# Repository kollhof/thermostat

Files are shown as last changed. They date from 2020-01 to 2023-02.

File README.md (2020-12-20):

# thermostat
ESP32 based thermostat for a DIY heating system

## gettting started

Create a factory NVS partitions with hardware and homekit config:

```bash
../esp-homekit-sdk/tools/mfg_homekit/hk_mfg_gen.py --conf mfg-config.csv --values mfg-values.csv --prefix thermo --cid 9 --outdir ./secret/mfg/ --size 0x6000
```

Flash factory partitions to individual devices:

```bash
esptool.py write_flash 0x340000 secret/mfg/bin/thermo-[homekit-setup-id].bin
```

Flash firmware:

```bash
idf.py clean build flash
```

Update firmware over the air:

The Device ID can be found as serial number in Homekit once paired.
```bash
idf.py -DOTA_DEVICE_ID=[device-id] clean build flash-ota
```

## progress

This first version used an ESP32-WROVER-V4 powered by a Hi-link power supply all badly soldered to a protboard with way too thick wires.

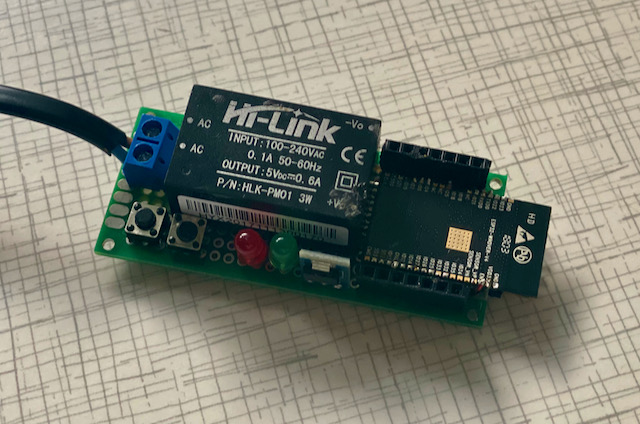
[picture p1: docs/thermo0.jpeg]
prototype 0


After reading up on powersupplies I decided to ditch the Hi-link for a Recom RAC03-05SK. It does not need any extra components to be safe which made things a bit simpler.

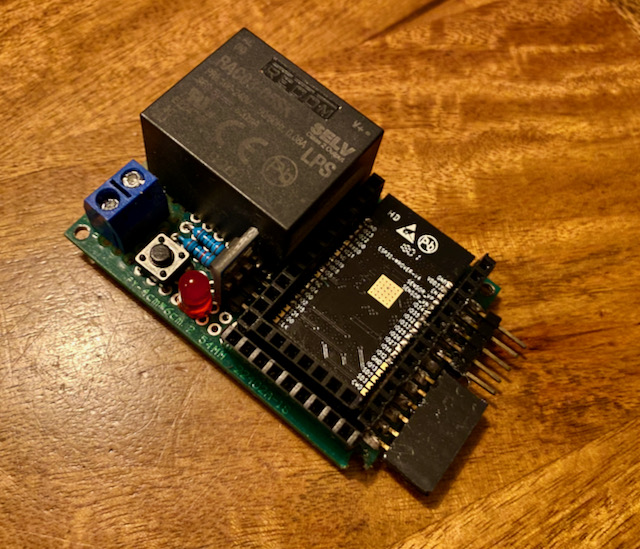
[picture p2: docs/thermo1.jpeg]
prototype 1


The female pin headers were awful to work with and I wanted a bit more ports exposed for experimenting.

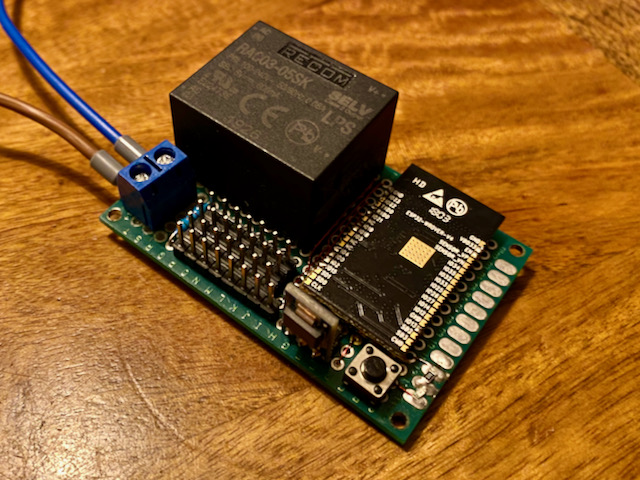
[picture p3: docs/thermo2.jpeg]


I also started to get a tiny bit better at soldering, and my choice of wires improved as well.

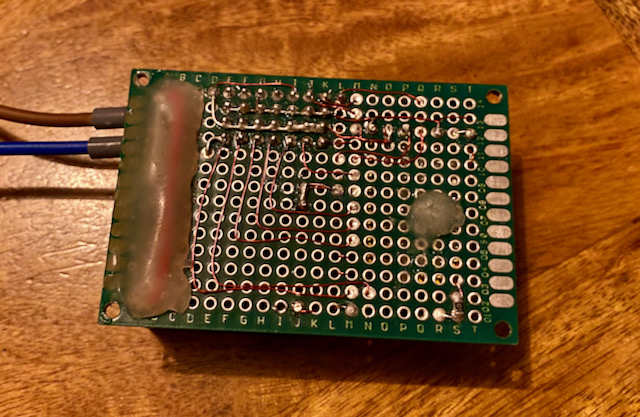
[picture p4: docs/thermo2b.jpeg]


Now I had a pretty well working little board. I used Dallas ds18b20 sensors to measure temperatur and relays to drive the electric radiators.

I needed about 5 of these boards, wiring and soldering everything got old pretty quickly. Instead of continuing to use protoboards, I decided to design my own PCB. I downloaded KiCad, looked at many ESP-32 dev board schematics for inspiration and created my own little board.

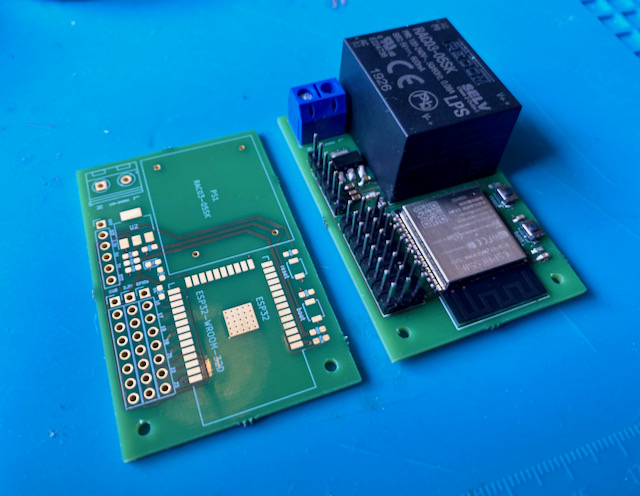
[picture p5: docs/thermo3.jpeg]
prototype 3


I had them printed by https://aisler.net and few days later I had a 3 PCBs and all the parts needed. I soldered all the SMD components using a hot air blower,and everything just worked!

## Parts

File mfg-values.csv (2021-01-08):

hw_model | hw_rev | gpio_led | gpio_pwm | gpio_temp | heat_min | heat_normal | heat_max | heat_cycle | ota_uri | ota_cert | mqtt_uri | root_cert_pem | client_cert_pem | client_key_pem
pico32 | 0.0.1 | 25 | 26 | 19 | 5 | 50 | 80 | 10 | secret/ota/ota-uri.txt | secret/ota/ota_ca_cert.pem | secret/aws/mqtt-uri.txt | secret/aws/aws-root-ca.pem | secret/aws/aws-certificate.pem.crt | secret/aws/aws-private.pem.key
proto1 | 0.0.1 | 18 | 27 | 25 | 5 | 50 | 80 | 10 | secret/ota/ota-uri.txt | secret/ota/ota_ca_cert.pem | secret/aws/mqtt-uri.txt | secret/aws/aws-root-ca.pem | secret/aws/aws-certificate.pem.crt | secret/aws/aws-private.pem.key
proto2 | 0.0.2 | 32 | 19 | 21 | 5 | 50 | 80 | 10 | secret/ota/ota-uri.txt | secret/ota/ota_ca_cert.pem | secret/aws/mqtt-uri.txt | secret/aws/aws-root-ca.pem | secret/aws/aws-certificate.pem.crt | secret/aws/aws-private.pem.key
proto4 | 0.0.4 | 13 | 22 | 23 | 5 | 50 | 80 | 10 | secret/ota/ota-uri.txt | secret/ota/ota_ca_cert.pem | secret/aws/mqtt-uri.txt | secret/aws/aws-root-ca.pem | secret/aws/aws-certificate.pem.crt | secret/aws/aws-private.pem.key
therm1 | 0.0.2 | 2 | 16 | 4 | 5 | 50 | 80 | 10 | secret/ota/ota-uri.txt | secret/ota/ota_ca_cert.pem | secret/aws/mqtt-uri.txt | secret/aws/aws-root-ca.pem | secret/aws/aws-certificate.pem.crt | secret/aws/aws-private.pem.key
therm1 | 0.0.2 | 2 | 16 | 4 | 5 | 50 | 80 | 10 | secret/ota/ota-uri.txt | secret/ota/ota_ca_cert.pem | secret/aws/mqtt-uri.txt | secret/aws/aws-root-ca.pem | secret/aws/aws-certificate.pem.crt | secret/aws/aws-private.pem.key
therm1 | 0.0.2 | 2 | 16 | 4 | 5 | 50 | 80 | 10 | secret/ota/ota-uri.txt | secret/ota/ota_ca_cert.pem | secret/aws/mqtt-uri.txt | secret/aws/aws-root-ca.pem | secret/aws/aws-certificate.pem.crt | secret/aws/aws-private.pem.key

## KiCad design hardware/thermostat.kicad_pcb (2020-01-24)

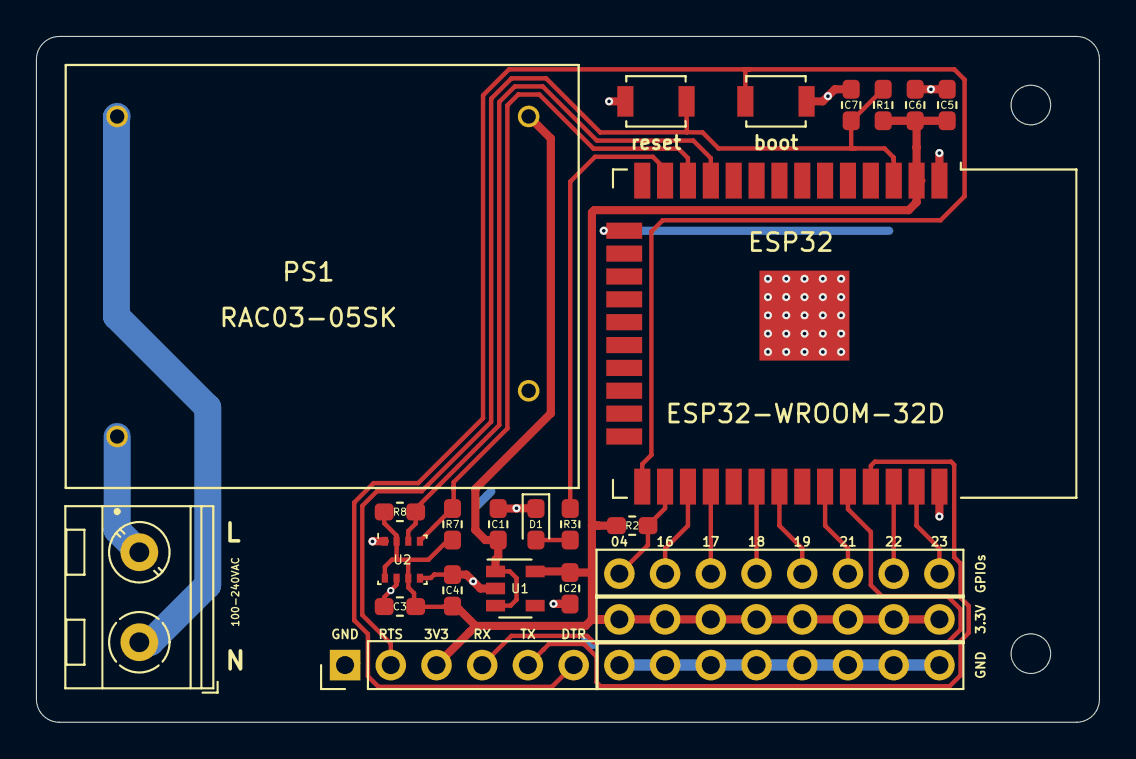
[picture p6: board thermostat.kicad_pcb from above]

Board: 2 copper layers, 59.1 x 38.1 mm, 27 parts (1 on the bottom side), 21 nets.

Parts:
C1: 1.0uF; C_0603_1608Metric_Pad1.05x0.95mm_HandSolder
C2: 2.2uF; C_0603_1608Metric_Pad1.05x0.95mm_HandSolder
C3, C4, C6, C7: 0.1uF; C_0603_1608Metric_Pad1.05x0.95mm_HandSolder
C5: 22uF; C_0603_1608Metric_Pad1.05x0.95mm_HandSolder
D1: status; LED_0603_1608Metric_Pad1.05x0.95mm_HandSolder
ESP32: ESP32-WROOM-32D; ESP32-WROOM-32
H1, H2: MountingHole; MountingHole_2.2mm_M2_ISO7380
J1: 230AC; TerminalBlock_RND_205-00045_1x02_P5.00mm_Horizontal
J2: program; PinHeader_1x06_P2.54mm_Vertical
J3: 3.3V; PinHeader_1x08_P2.54mm_Vertical
J4: GND; PinHeader_1x08_P2.54mm_Vertical
J5: GPIOs; PinHeader_1x08_P2.54mm_Vertical
LOGO1: Logo_Open_Hardware_Small; OSHW-Symbol_6.7x6mm_SilkScreen
PS1: RAC03-05SK; CONV_RAC03-05SK
R1: 10K; R_0603_1608Metric_Pad1.05x0.95mm_HandSolder
R2, R7, R8: 4.7k; R_0603_1608Metric_Pad1.05x0.95mm_HandSolder
R3: 1k; R_0603_1608Metric_Pad1.05x0.95mm_HandSolder
SW1: reset; SW_SPST_B3U-1000P
SW2: boot; SW_SPST_B3U-1000P
U1: AP2112K-3.3; SOT-23-5
U2: BME280; Bosch_LGA-8_2.5x2.5mm_P0.65mm_ClockwisePinNumbering

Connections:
+3V3: C2.1, C3.1, C4.1, C5.1, C6.1, ESP32.2, J2.3, J3.1, J3.2, J3.3, J3.4, J3.5, J3.6, J3.7, J3.8, R1.1, R2.1, R7.1, R8.1, U1.5, U2.2, U2.6, U2.8
+5V: C1.1, PS1.3, U1.1, U1.3
/L: J1.2, PS1.1
/N: J1.1, PS1.4
EN: C7.2, ESP32.3, J2.2, R1.2, SW1.2
GND: C1.2, C2.2, C3.2, C4.2, C5.2, C6.2, C7.1, D1.1, ESP32.1, ESP32.15, ESP32.38, ESP32.39, J2.1, J4.1, J4.2, J4.3, J4.4, J4.5, J4.6, J4.7, J4.8, PS1.2, SW1.1, SW2.1, U1.2, U2.1, U2.5, U2.7
IO4: ESP32.26, J5.1, R2.2
IO14: ESP32.13, R3.1
IO16: ESP32.27, J5.2
IO17: ESP32.28, J5.3
IO18: ESP32.30, J5.4
IO19: ESP32.31, J5.5
IO21: ESP32.33, J5.6
IO22: ESP32.36, J5.7
IO23: ESP32.37, J5.8
IO26: ESP32.11, R8.2, U2.3
IO27: ESP32.12, R7.2, U2.4
unnamed: D1.2, R3.2
RX: ESP32.34, J2.4
TX: ESP32.35, J2.5
boot: ESP32.25, J2.6, SW2.2

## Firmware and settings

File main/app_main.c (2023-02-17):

#include "sdkconfig.h"

#include "freertos/FreeRTOS.h"

#include "esp_log.h"
#include "esp_task_wdt.h"
#include "esp_event.h"
#include "esp_https_ota.h"
#include "esp_gatt_defs.h"
#include "nvs_flash.h"
#include "mqtt_client.h"
#include "unistd.h"
#include "driver/gpio.h"

#include "./app_wifi.h"
#include "./app_homekit.h"
#include "./app_mqtt.h"
#include "./app_timekeeper.h"
#include "./app_thermostat.h"
#include "./app_thermometer.h"
#include "./app_ota.h"
#include "./app_events.h"
#include "./app_restarter.h"
#include "./app_stats.h"


static const char* TAG = "app";


typedef struct {
  char * hw_model;
  char * hw_serial;
  char * hw_rev;

  uint8_t gpio_pwm;
  uint8_t gpio_temp;
  uint8_t gpio_led;
  uint8_t heat_min;
  uint8_t heat_normal;
  uint8_t heat_max;
  uint8_t heat_cycle_sec;
  float target_temp;

  esp_bd_addr_t ble_themometer_addr;

  char * mqtt_uri;
  char * mqtt_root_ca;
  char * mqtt_client_cert;
  char * mqtt_client_key;

  char * ota_uri;
  char * ota_cert;

} app_config_t;




static void init_logging() {
  esp_log_level_set("*", ESP_LOG_VERBOSE);
  esp_log_level_set("nvs", ESP_LOG_VERBOSE);
  esp_log_level_set("MQTT_CLIENT", ESP_LOG_VERBOSE);
  esp_log_level_set("TRANSPORT_TCP", ESP_LOG_VERBOSE);
  esp_log_level_set("TRANSPORT_SSL", ESP_LOG_VERBOSE);
  esp_log_level_set("TRANSPORT", ESP_LOG_VERBOSE);
  esp_log_level_set("OUTBOX", ESP_LOG_VERBOSE);
  esp_log_level_set("BTDM_INIT", ESP_LOG_VERBOSE);
  esp_log_level_set("simple_ble", ESP_LOG_VERBOSE);

  ESP_LOGI(TAG, "logging initialized");
}



static void init_nvs() {
  ESP_LOGI(TAG, "init nvs");

  esp_err_t ret = nvs_flash_init();
  if (ret == ESP_ERR_NVS_NO_FREE_PAGES || ret == ESP_ERR_NVS_NEW_VERSION_FOUND) {
    ESP_ERROR_CHECK(nvs_flash_erase());
    ret = nvs_flash_init();
  }
  ESP_ERROR_CHECK(ret);

  ESP_ERROR_CHECK(nvs_flash_init_partition("factory_nvs"));
}



static void init_system() {
  init_logging();

  ESP_LOGI(TAG, "starting app...");
  ESP_LOGI(TAG, "free memory: %d bytes", esp_get_free_heap_size());
  ESP_LOGI(TAG, "IDF version: %s", esp_get_idf_version());

  esp_event_loop_create_default();

  init_nvs();
}



static esp_err_t get_u8(nvs_handle_t handle, const char *key, uint8_t *out_value) {
  esp_err_t err = nvs_get_u8(handle, key, out_value);
  if (err != ESP_OK) {
    ESP_LOGE(TAG, "Error reading %s: %s NVS", key, esp_err_to_name(err));
  } else {
    ESP_LOGI(TAG, "Loaded %s: %u", key, *out_value);
  }
  return err;
}


static esp_err_t get_str(nvs_handle_t handle, const char *key, char **out_value) {
  size_t required_size;

  esp_err_t err = nvs_get_str(handle, key, NULL, &required_size);
  if (err != ESP_OK) {
    ESP_LOGE(TAG, "Error reading %s: %s NVS", key, esp_err_to_name(err));
  } else {
    char* value = malloc(required_size);
    nvs_get_str(handle, key, value, &required_size);
    ESP_LOGI(TAG, "Loaded %s: %s", key, value);
    *out_value = value;
  }
  return err;
}


static esp_err_t get_blob(nvs_handle_t handle, const char *key, char *out_value) {
  size_t required_size;

  esp_err_t err = nvs_get_blob(handle, key, NULL, &required_size);
  if (err != ESP_OK) {
    ESP_LOGE(TAG, "Error reading %s: %s NVS", key, esp_err_to_name(err));
  } else {
    nvs_get_blob(handle, key, out_value, &required_size);
    ESP_LOGI(TAG, "Loaded %s: %d", key, required_size);
    esp_log_buffer_hex(TAG, (char *) out_value, required_size);
  }
  return err;
}



char * get_serial_number() {
  uint8_t mac[6] = {0};
  esp_efuse_mac_get_default(mac);

  char * str = malloc(16);
  snprintf(str, 16, "%02x%02x-%02x%02x-%02x%02x", mac[0], mac[1], mac[2], mac[3], mac[4], mac[5]);
  return str;
}



static esp_err_t init_app_config(app_config_t * config) {
  ESP_LOGI(TAG, "init config...");


  config->hw_serial = get_serial_number();

  nvs_handle handle;
  esp_err_t err = nvs_open_from_partition("factory_nvs", "app", NVS_READONLY, &handle);
  if (err != ESP_OK) {
    ESP_LOGE(TAG, "Error (%s) opening NVS handle for 'factory_nvs:app'", esp_err_to_name(err));
    return err;
  }

  err = get_str(handle, "hw_model", &config->hw_model);
  err = get_str(handle, "hw_rev", &config->hw_rev);

  err = get_u8(handle, "gpio_pwm", &config->gpio_pwm);
  err = get_u8(handle, "gpio_temp", &config->gpio_temp);
  err = get_u8(handle, "gpio_led", &config->gpio_led);

  err = get_u8(handle, "heat_min", &config->heat_min);
  err = get_u8(handle, "heat_normal", &config->heat_normal);
  err = get_u8(handle, "heat_max", &config->heat_max);
  err = get_u8(handle, "heat_cycle", &config->heat_cycle_sec);

  err = get_blob(handle, "ble_thermo_addr", (char *) &config->ble_themometer_addr);

  err = get_str(handle, "mqtt_uri", &config->mqtt_uri);
  err = get_str(handle, "root_cert_pem", &config->mqtt_root_ca);
  err = get_str(handle, "client_cert_pem", &config->mqtt_client_cert);
  err = get_str(handle, "client_key_pem", &config->mqtt_client_key);

  err = get_str(handle, "ota_uri", &config->ota_uri);
  err = get_str(handle, "ota_cert", &config->ota_cert);

  nvs_close(handle);

  return err;
}



static float load_target_temp(float default_target_temp) {
  float target_temp = default_target_temp;

  nvs_handle_t nvs_handle;
  esp_err_t err = nvs_open("storage", NVS_READWRITE, &nvs_handle);

  if (err != ESP_OK) {
    ESP_LOGE(TAG, "Error (%s) opening NVS handle!", esp_err_to_name(err));
  } else {

    err = nvs_get_u32(nvs_handle, "target_temp", (uint32_t*)&target_temp);
    switch (err) {
      case ESP_OK:
        ESP_LOGI(TAG, "Read target_temp %0.3f from storage", target_temp);
        break;

      case ESP_ERR_NVS_NOT_FOUND:
        ESP_LOGE(TAG, "The target_temp is not in storage yet!");
        target_temp = default_target_temp;
        break;

      default :
        ESP_LOGE(TAG, "Error (%s) reading NVS", esp_err_to_name(err));
        target_temp = default_target_temp;
        break;
    }

    nvs_close(nvs_handle);
  }

  return target_temp;
}


static void patch_config() {

  nvs_handle_t nvs_handle;
  esp_err_t err = nvs_open_from_partition("factory_nvs", "app", NVS_READWRITE, &nvs_handle);

  if (err != ESP_OK) {
    ESP_LOGE(TAG, "Error (%s) opening NVS handle!", esp_err_to_name(err));
  } else {
    // nvs_set_u8(nvs_handle, "heat_min", 5);
    // nvs_set_u8(nvs_handle, "heat_normal", 50);
    // nvs_set_u8(nvs_handle, "heat_max", 70);

    // err = nvs_commit(nvs_handle);
    // if (err != ESP_OK) {
    //   ESP_LOGE(TAG, "Error (%s) committing storage", esp_err_to_name(err));
    // }

    nvs_close(nvs_handle);
  }
}



void app_main(void) {
  ESP_LOGI(TAG, "starting...");
  init_system();

  patch_config();

  app_config_t conf = {
    .gpio_pwm = 25,
    .gpio_temp = 26,
    .gpio_led = 27,
    .heat_min = 15,
    .heat_normal = 50,
    .heat_max = 70,
    .heat_cycle_sec = 1,
    .target_temp = load_target_temp(15),
    .ble_themometer_addr = {0},
  };
  init_app_config(&conf);

  esp_http_client_config_t ota_config = {
    .url = conf.ota_uri,
    .cert_pem = conf.ota_cert,
  };

  esp_mqtt_client_config_t mqtt_config = {
    .uri = conf.mqtt_uri,
    .cert_pem = conf.mqtt_root_ca,
    .client_cert_pem = conf.mqtt_client_cert,
    .client_key_pem = conf.mqtt_client_key,
  };

  app_init_networking(conf.hw_serial);

  app_start_mqtt(&mqtt_config, conf.hw_serial);

  app_start_networking(portMAX_DELAY);

  app_start_homekit(conf.hw_model, conf.hw_rev, conf.hw_serial, conf.target_temp);

  app_start_thermometer(conf.gpio_temp, conf.ble_themometer_addr);

  app_start_restart_handler();

  app_start_ota_handler(&ota_config);

  app_start_timekeeper();

  app_start_stats_handler(conf.gpio_led);

  app_start_thermostat(
    conf.gpio_pwm,
    conf.heat_min, conf.heat_normal, conf.heat_max,
    conf.heat_cycle_sec,
    conf.target_temp
  );

  app_post_event(APP_EVENT_STARTED, NULL, 0);

  // TODO: should wait for a restart event
  ESP_LOGI(TAG, "all tasks started");
  while (true) {
    sleep(1);
  }
  // fflush(stdout);
  // esp_restart();
}

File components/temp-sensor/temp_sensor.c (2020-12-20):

#include <stdio.h>
#include <math.h>
#include <string.h>

#include "stdatomic.h"
#include "sdkconfig.h"
#include "freertos/FreeRTOS.h"
#include "freertos/task.h"
#include "esp_task.h"
#include "esp_system.h"
#include "esp_log.h"
#include "esp_sleep.h"
#include "unistd.h"

#include "owb.h"
#include "owb_rmt.h"
#include "ds18b20.h"

#include "./temp_sensor.h"


#define MAX_DEVICES 10
#define DS18B20_RESOLUTION 12
#define STACK_SIZE 5048


static const char* TAG = "temp-sensor";


typedef struct {
  owb_rmt_driver_info driver_info;
  OneWireBus * bus;
  uint8_t num_devices;
  DS18B20_Info * devices[10];
} Sensors;


static double exp_weighted_moving_avg(double prev_value, double value, double alpha) {
  return ((1.0-alpha) * prev_value) + (alpha * value);
}


static int find_devices(OneWireBus *owb, OneWireBus_ROMCode device_rom_codes[]) {
  ESP_LOGI(TAG, "finding devices");

  int num_devices = 0;

  OneWireBus_SearchState search_state = {0};
  bool found = false;

  owb_search_first(owb, &search_state, &found);

  while (found) {
    char rom_code_s[17];
    owb_string_from_rom_code(search_state.rom_code, rom_code_s, sizeof(rom_code_s));
    ESP_LOGI(TAG, " %d : %s", num_devices, rom_code_s);

    device_rom_codes[num_devices] = search_state.rom_code;
    ++num_devices;
    owb_search_next(owb, &search_state, &found);
  }

  if (num_devices == 1) {
    // For a single device only:
    OneWireBus_ROMCode rom_code;
    owb_status status = owb_read_rom(owb, &rom_code);

    if (status == OWB_STATUS_OK) {
      char rom_code_s[OWB_ROM_CODE_STRING_LENGTH];
      owb_string_from_rom_code(rom_code, rom_code_s, sizeof(rom_code_s));
      ESP_LOGI(TAG, "Single device %s present", rom_code_s);
    } else {
      ESP_LOGE(TAG, "An error occurred reading device ROM code: %d", status);
    }
  }

  ESP_LOGI(TAG, "found %d devices", num_devices);
  return num_devices;
}


static void sensors_init(Sensors * sensors, uint8_t gpio) {
  ESP_LOGI(TAG, "setting up OneWire on GPIO %d", gpio);

  // Create a 1-Wire bus, using the RMT timeslot driver
  sensors->bus = owb_rmt_initialize(
    &(sensors->driver_info), gpio,
    RMT_CHANNEL_1, RMT_CHANNEL_0
  );
  owb_use_crc(sensors->bus, true);  // enable CRC check for ROM code

  OneWireBus_ROMCode device_rom_codes[MAX_DEVICES] = {0};

  int num_devices = find_devices(sensors->bus, device_rom_codes);

  sensors->num_devices = num_devices;

  for (int i = 0; i < num_devices; ++i) {
    DS18B20_Info * ds18b20_info = ds18b20_malloc();
    sensors->devices[i] = ds18b20_info;

    if (num_devices == 1) {
      ESP_LOGI(TAG, "Single device optimisations enabled");
      ds18b20_init_solo(ds18b20_info, sensors->bus);
    } else {
      ds18b20_init(ds18b20_info, sensors->bus, device_rom_codes[i]);
    }
    ds18b20_use_crc(ds18b20_info, true);
    ds18b20_set_resolution(ds18b20_info, DS18B20_RESOLUTION);
  }

  ESP_LOGI(TAG, "sensors initialized");
}


static float read_temperature(Sensors * sensors) {
  float reading = 0;

  if (sensors->num_devices > 0) {
    DS18B20_Info * device = sensors->devices[0];
    ds18b20_convert_all(device->bus);
    ds18b20_wait_for_conversion(device);
    DS18B20_ERROR err = ds18b20_read_temp(device, &reading);

    if (err == DS18B20_OK) {
      return reading;
    }

    ESP_LOGE(TAG, "error reading temp %u", err);
  } else {

    ESP_LOGE(TAG, "no temp devices found");
  }

  return 100;
}


static void atomic_store_float(atomic_uint_fast32_t* dest, float value) {
  const uint32_t store_value = *(uint32_t *)&value;
  atomic_store(dest, store_value);
}


static float atomic_load_float(atomic_uint_fast32_t* src) {
  const uint32_t value = atomic_load(src);
  return *(float*)&value;
}


static void temp_task(void * arg) {
  temp_sensor_t * temp_sensor = (temp_sensor_t *) arg;

  Sensors sensors;
  sensors_init(&sensors, temp_sensor->gpio_num);

  double avg_temp = 18.0;
  double alpha = 0.2;


  while(true) {
    TickType_t start_time = xTaskGetTickCount();

    const float temp = read_temperature(&sensors);

    avg_temp = exp_weighted_moving_avg(avg_temp, temp, alpha);

    atomic_store_float(&(temp_sensor->curr_temp), avg_temp);

    const TickType_t end_time = xTaskGetTickCount();
    const float duration = (end_time-start_time) * portTICK_PERIOD_MS;

    ESP_LOGI(TAG, "read temp %0.2f (avg %0.2f) in %f ms", temp, avg_temp, duration);

    vTaskDelayUntil(&start_time, temp_sensor->read_interval / portTICK_PERIOD_MS);
  }
}


double get_temperature(temp_sensor_t * temp_sensor) {
  return atomic_load_float(&(temp_sensor->curr_temp));
}


temp_sensor_t * start_temp_sensors(gpio_num_t gpio_num, uint64_t read_interval) {
  ESP_LOGI(TAG, "starting temp-sensors task ...");

  temp_sensor_t * temp_sensor = malloc(sizeof(temp_sensor_t));
  *temp_sensor = (temp_sensor_t) {
    .gpio_num = gpio_num,
    .read_interval = read_interval
  };
  xTaskCreate(temp_task, "temp-sensor", STACK_SIZE, temp_sensor, ESP_TASK_MAIN_PRIO, &temp_sensor->task_handle);

  ESP_LOGI(TAG, "started temp-sensors task");
  return temp_sensor;
}


void stop_temp_sensors(temp_sensor_t * temp_sensor) {
  ESP_LOGI(TAG, "stopping temp-sensors ...");

  // TODO: free up
  // ds18b20_free(&devices[i]);
  // owb_uninitialize(owb);

  vTaskDelete(temp_sensor->task_handle);
  ESP_LOGI(TAG, "stopped temp-sensors");
}

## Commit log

2020-01-06 adding board config and stats reporting
2020-01-19 correct board ID
2020-01-24 add KiCad files for custom PCBs
    [thermostat.kicad_pcb, thermostat.sch]
2020-01-29 add new board
2020-02-01 trying out modulation of power to heating vs on off
2020-12-02 fix temp threshhold, allow config of duty cycle length for using short cycles with SSRs
    [app_main.c, app_stats.c, app_thermostat.c]
2020-12-08 feat(led): dim LED based on heating state
2020-12-20 add native support for homekit, simplify firmware upgrade by using a factory partition with board configs, add support for unified provisioning
    [mfg-config.csv, mfg-values.csv, partitions.csv]
2021-01-08 add support for BLE temp sensors
    [mfg-config.csv, mfg-values.csv, thermostat.sch]
2021-11-21 add support for signaling ow battary fault when BLE temp sensor cannot be read
2022-12-08 remove wired temp sensor, add watchdog for BLE sensor

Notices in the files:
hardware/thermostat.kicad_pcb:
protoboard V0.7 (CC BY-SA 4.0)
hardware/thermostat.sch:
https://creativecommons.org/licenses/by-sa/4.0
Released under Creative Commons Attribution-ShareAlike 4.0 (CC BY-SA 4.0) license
